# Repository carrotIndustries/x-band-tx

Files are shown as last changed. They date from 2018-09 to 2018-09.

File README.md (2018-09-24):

# X Band Transmitter

This project has been my master thesis at the University of Stuttgart at the Institute of Robust Power Semiconductor Systems (ILH) and the Institute of Space Systems (IRS). It's part of larger project of developing a data downlink system (DDS) for an upcoming small satellite.

The transmitter supports a bandwidth of approx 50 MHz at center frequency of nominally 10.475 GHz. Complex baseband data is played back from a 32 KiSa block RAM in the FPGA. For writing data to the block RAM and setting up PLL and DAC, a USB/SPI bridge is included on the board.

I'd like to thank my tutors for allowing me to use my back then largely untested EDA package horizon EDA. Thanks to them I've now got a project to show off what horizon EDA is capable of.

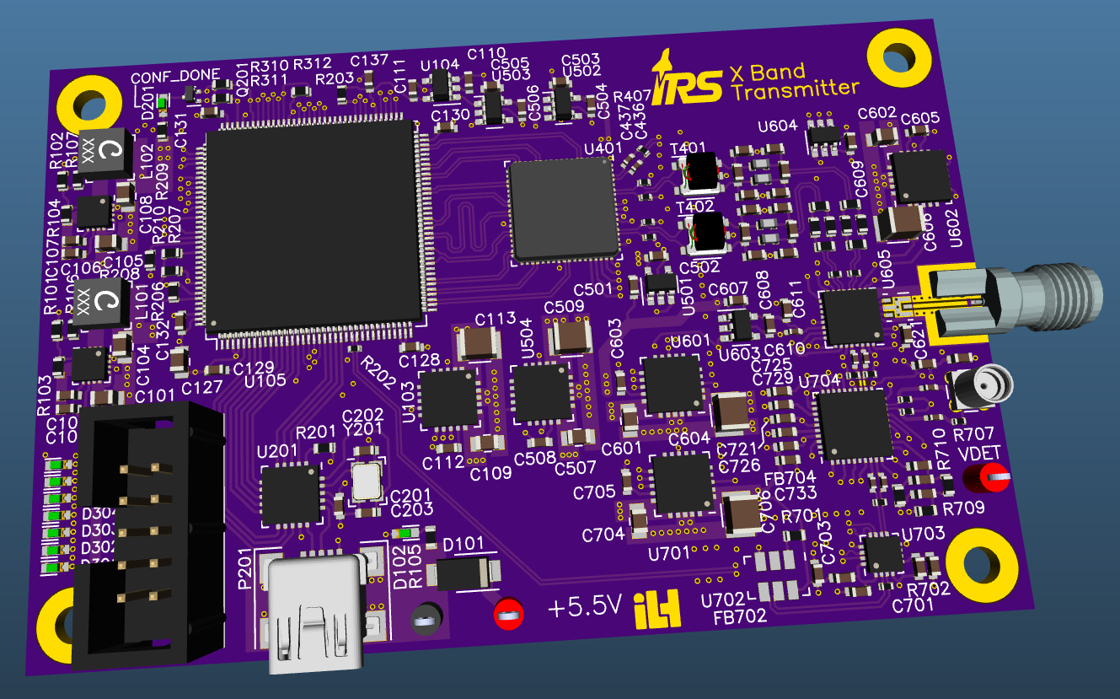
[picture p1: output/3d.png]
PCB


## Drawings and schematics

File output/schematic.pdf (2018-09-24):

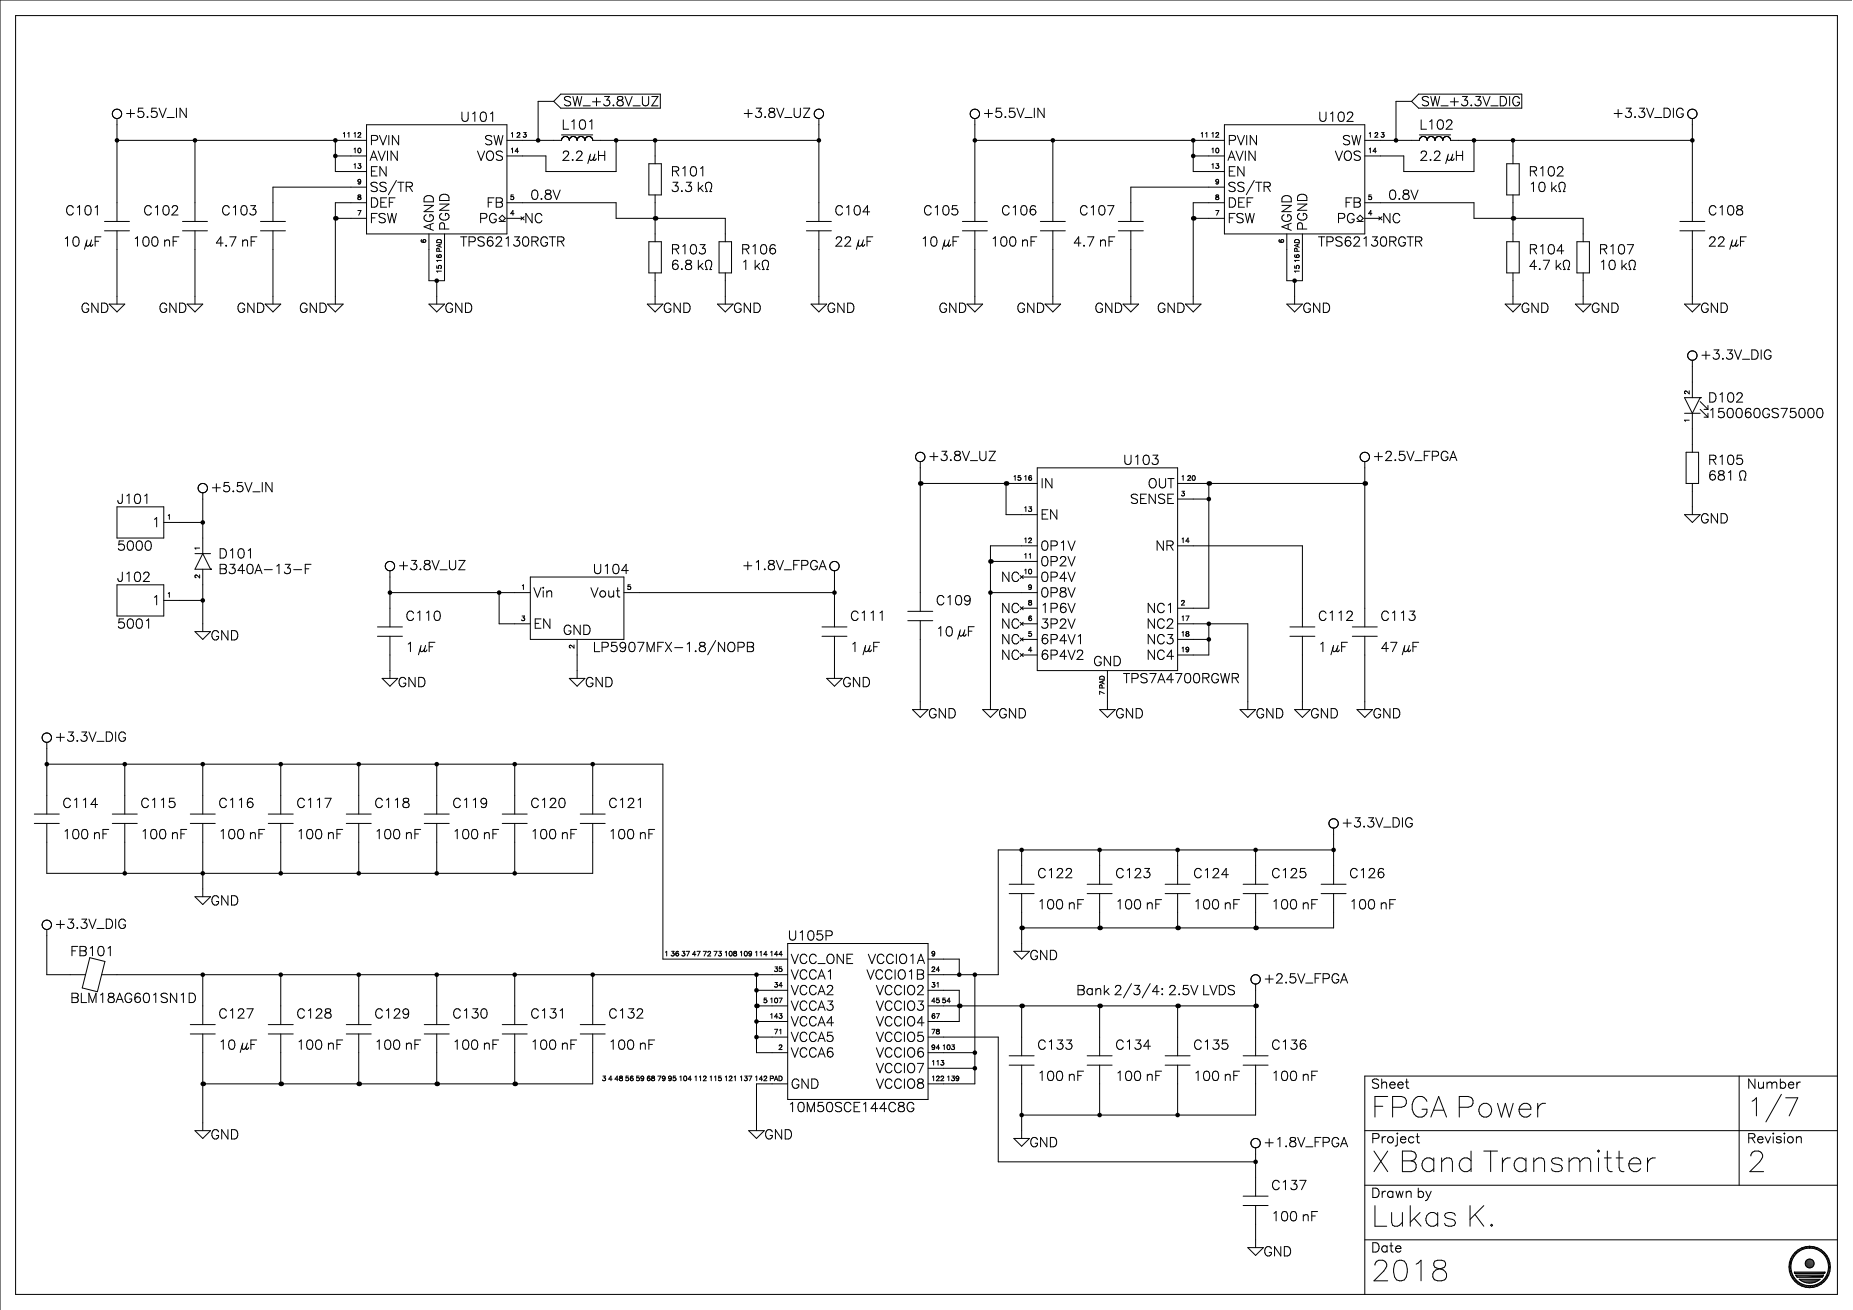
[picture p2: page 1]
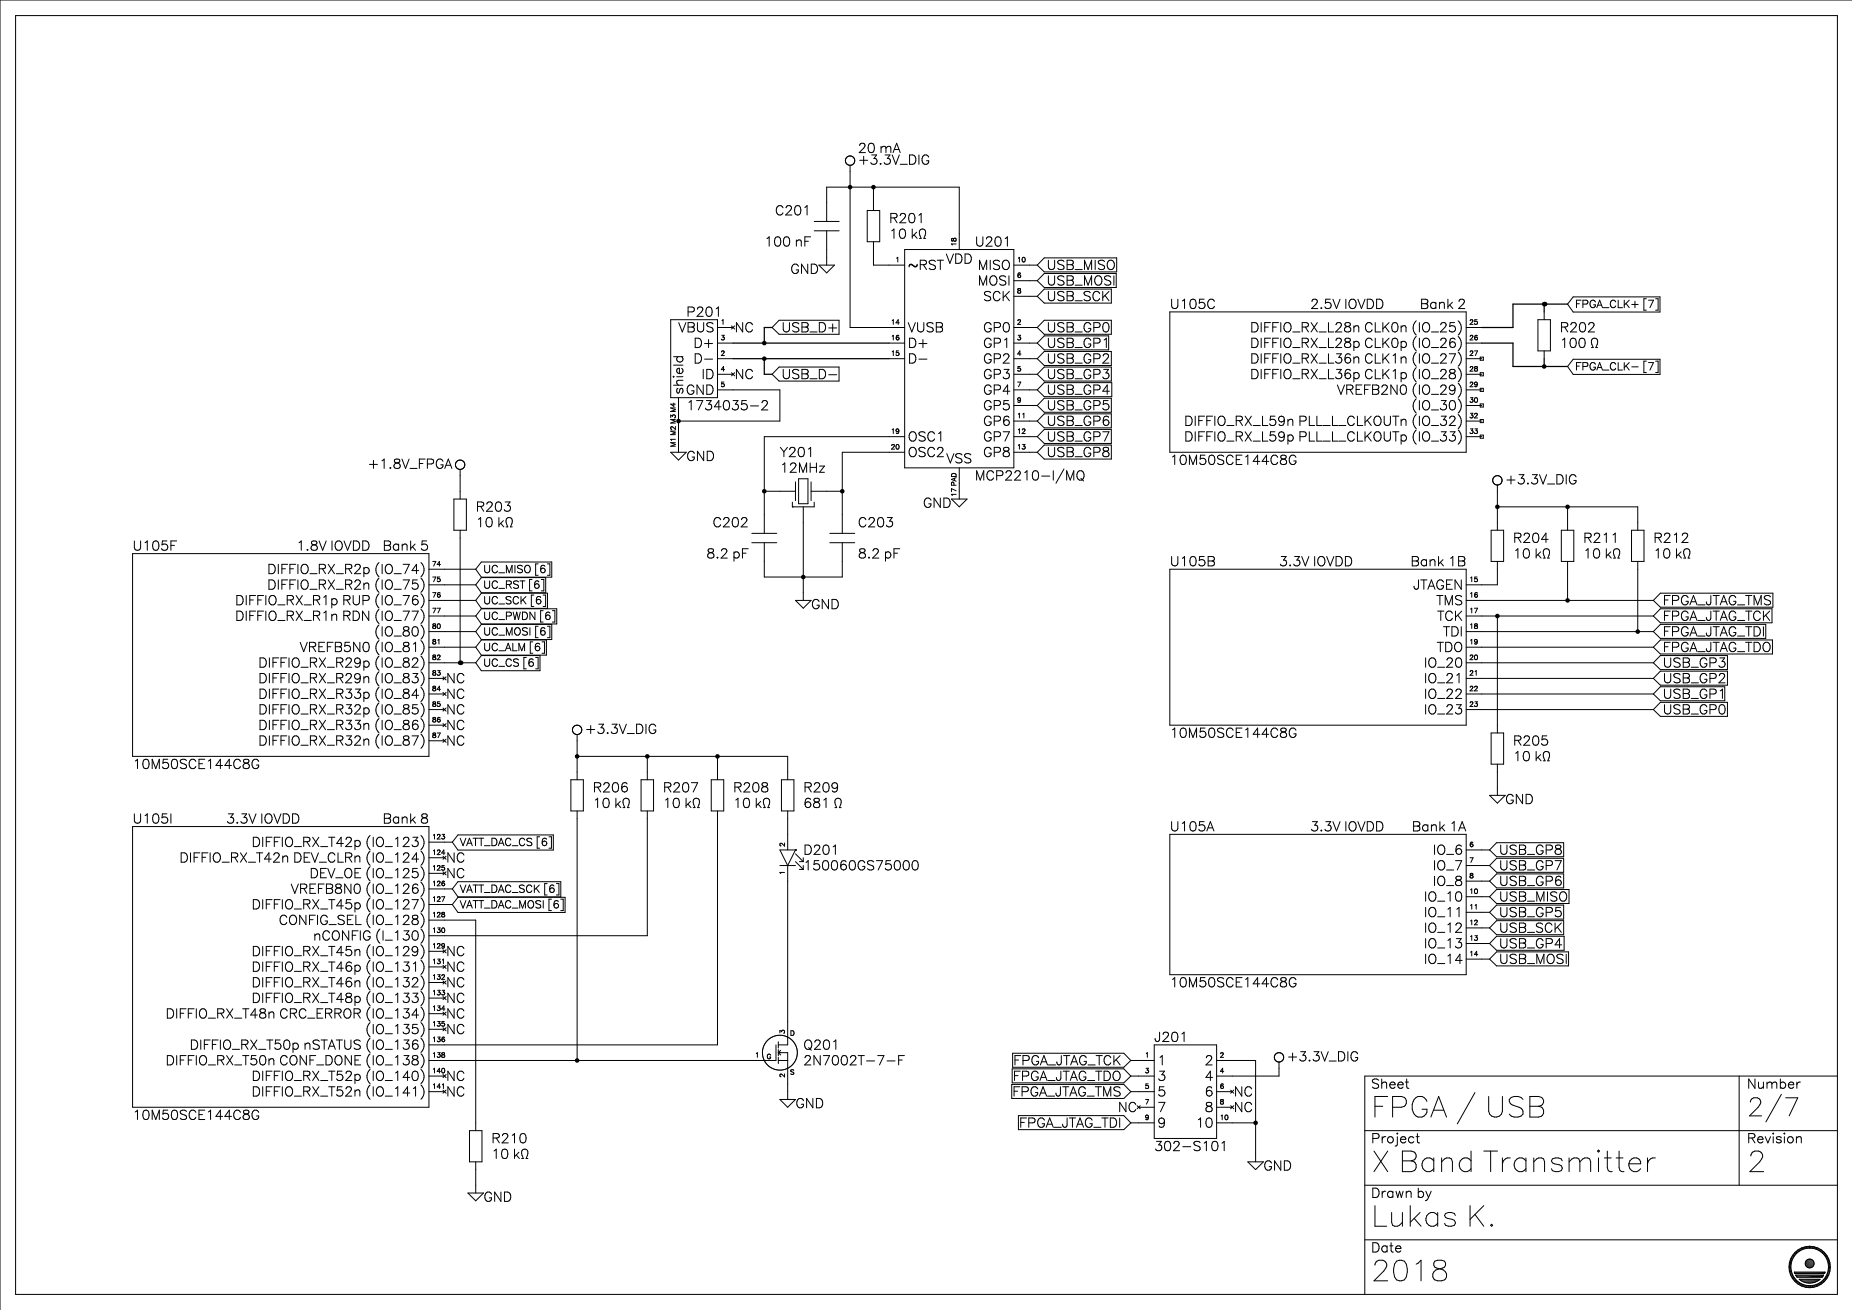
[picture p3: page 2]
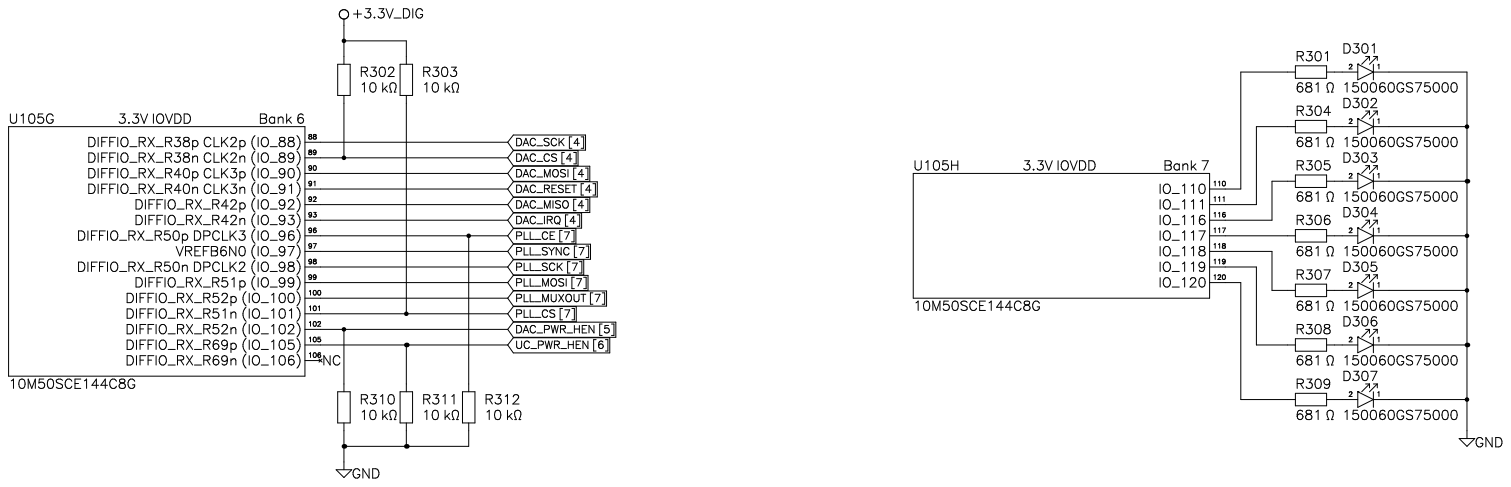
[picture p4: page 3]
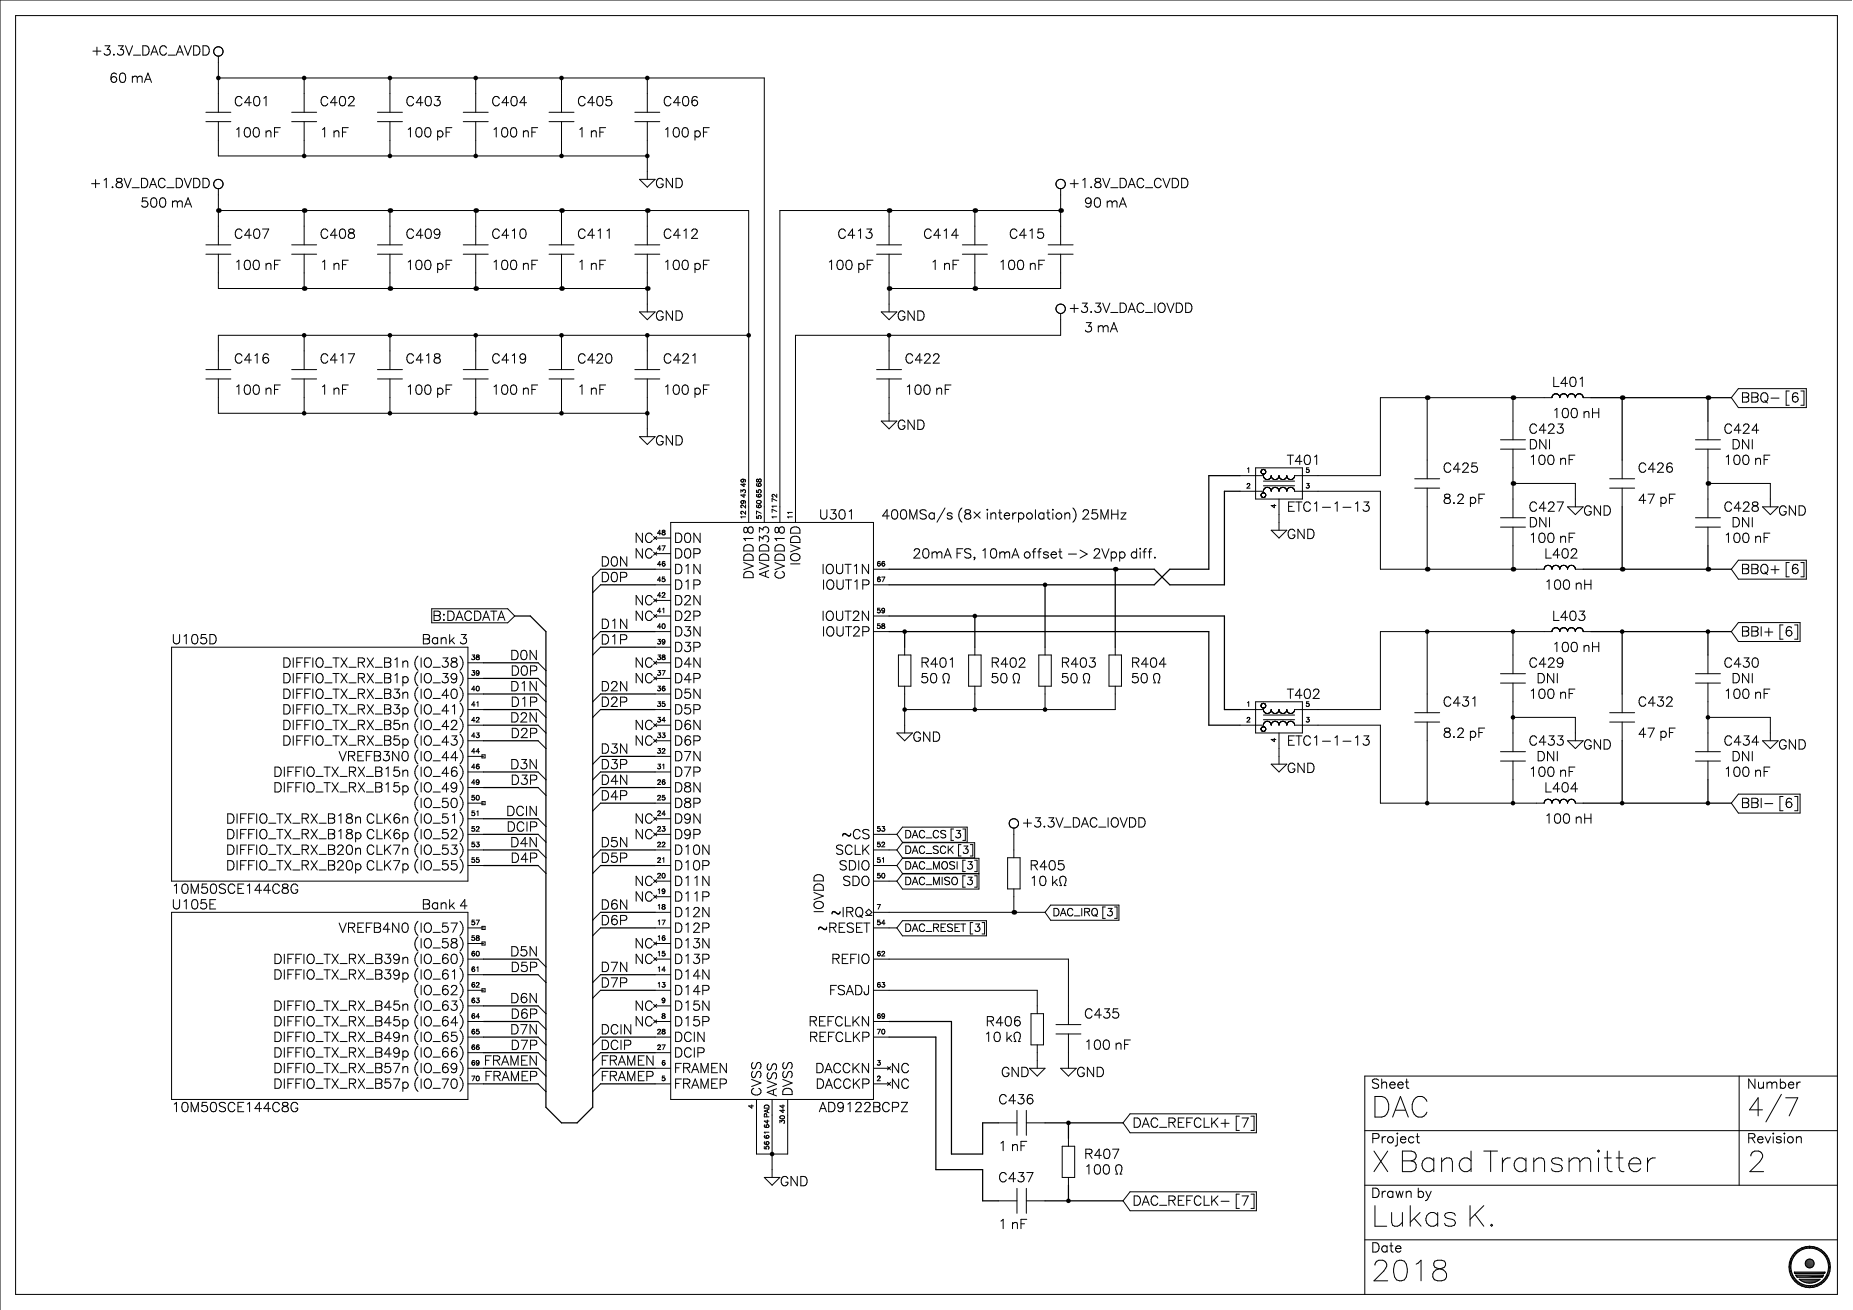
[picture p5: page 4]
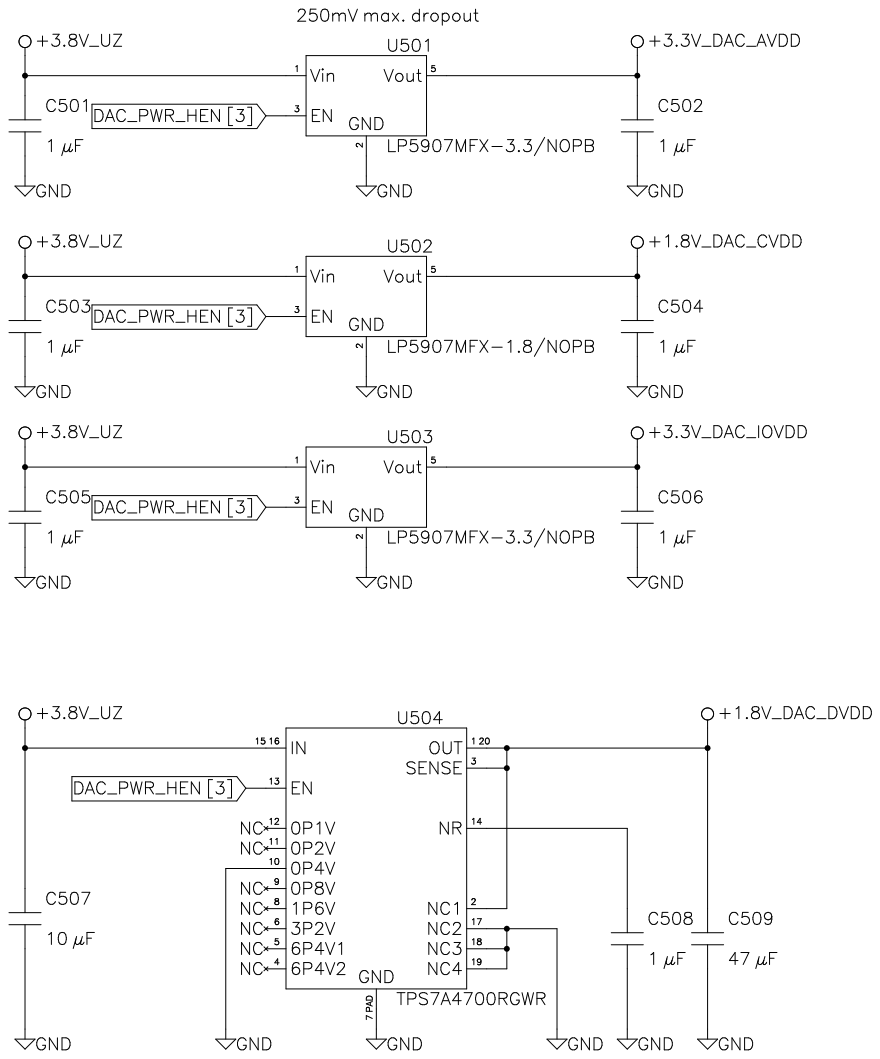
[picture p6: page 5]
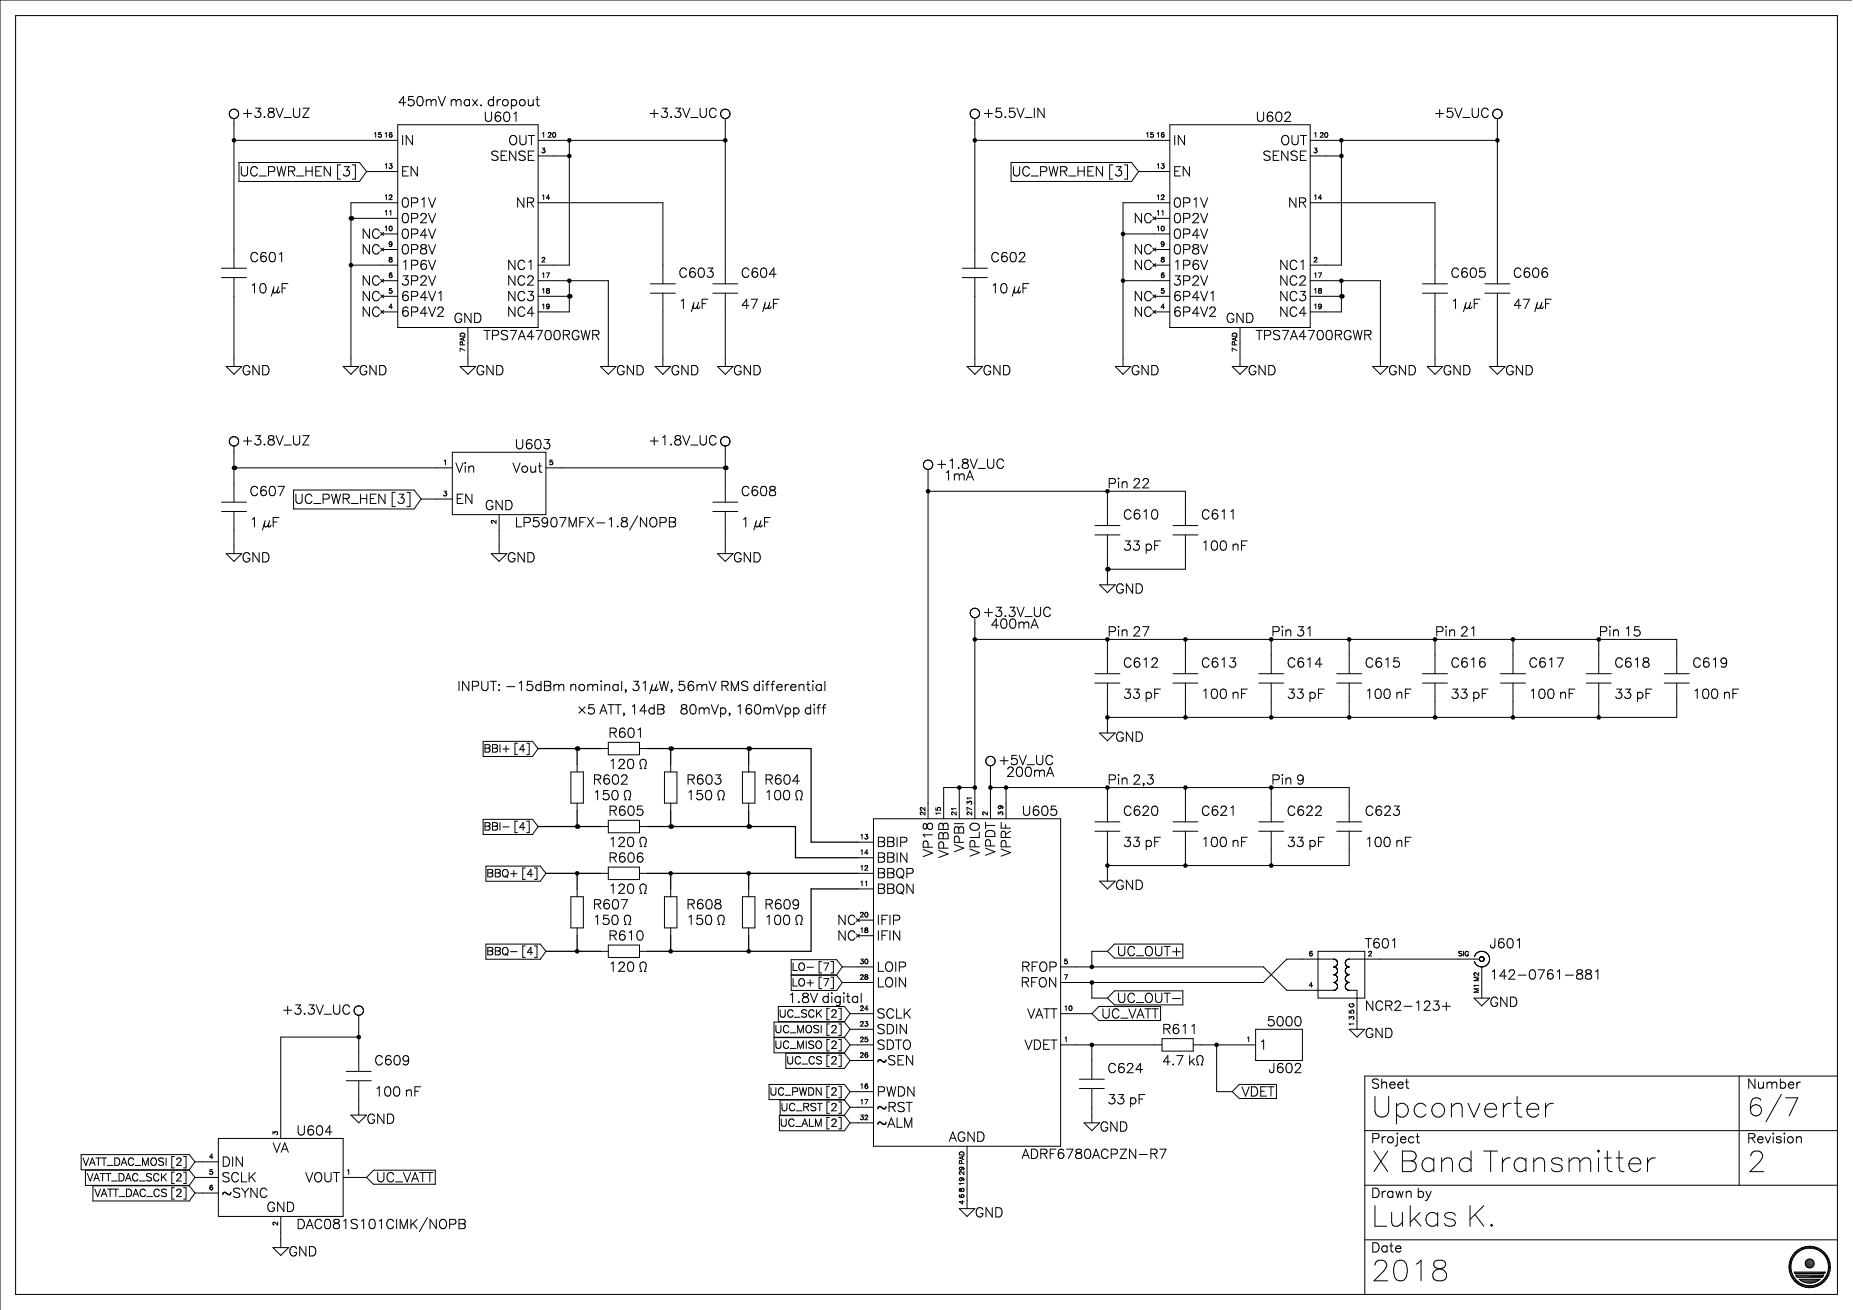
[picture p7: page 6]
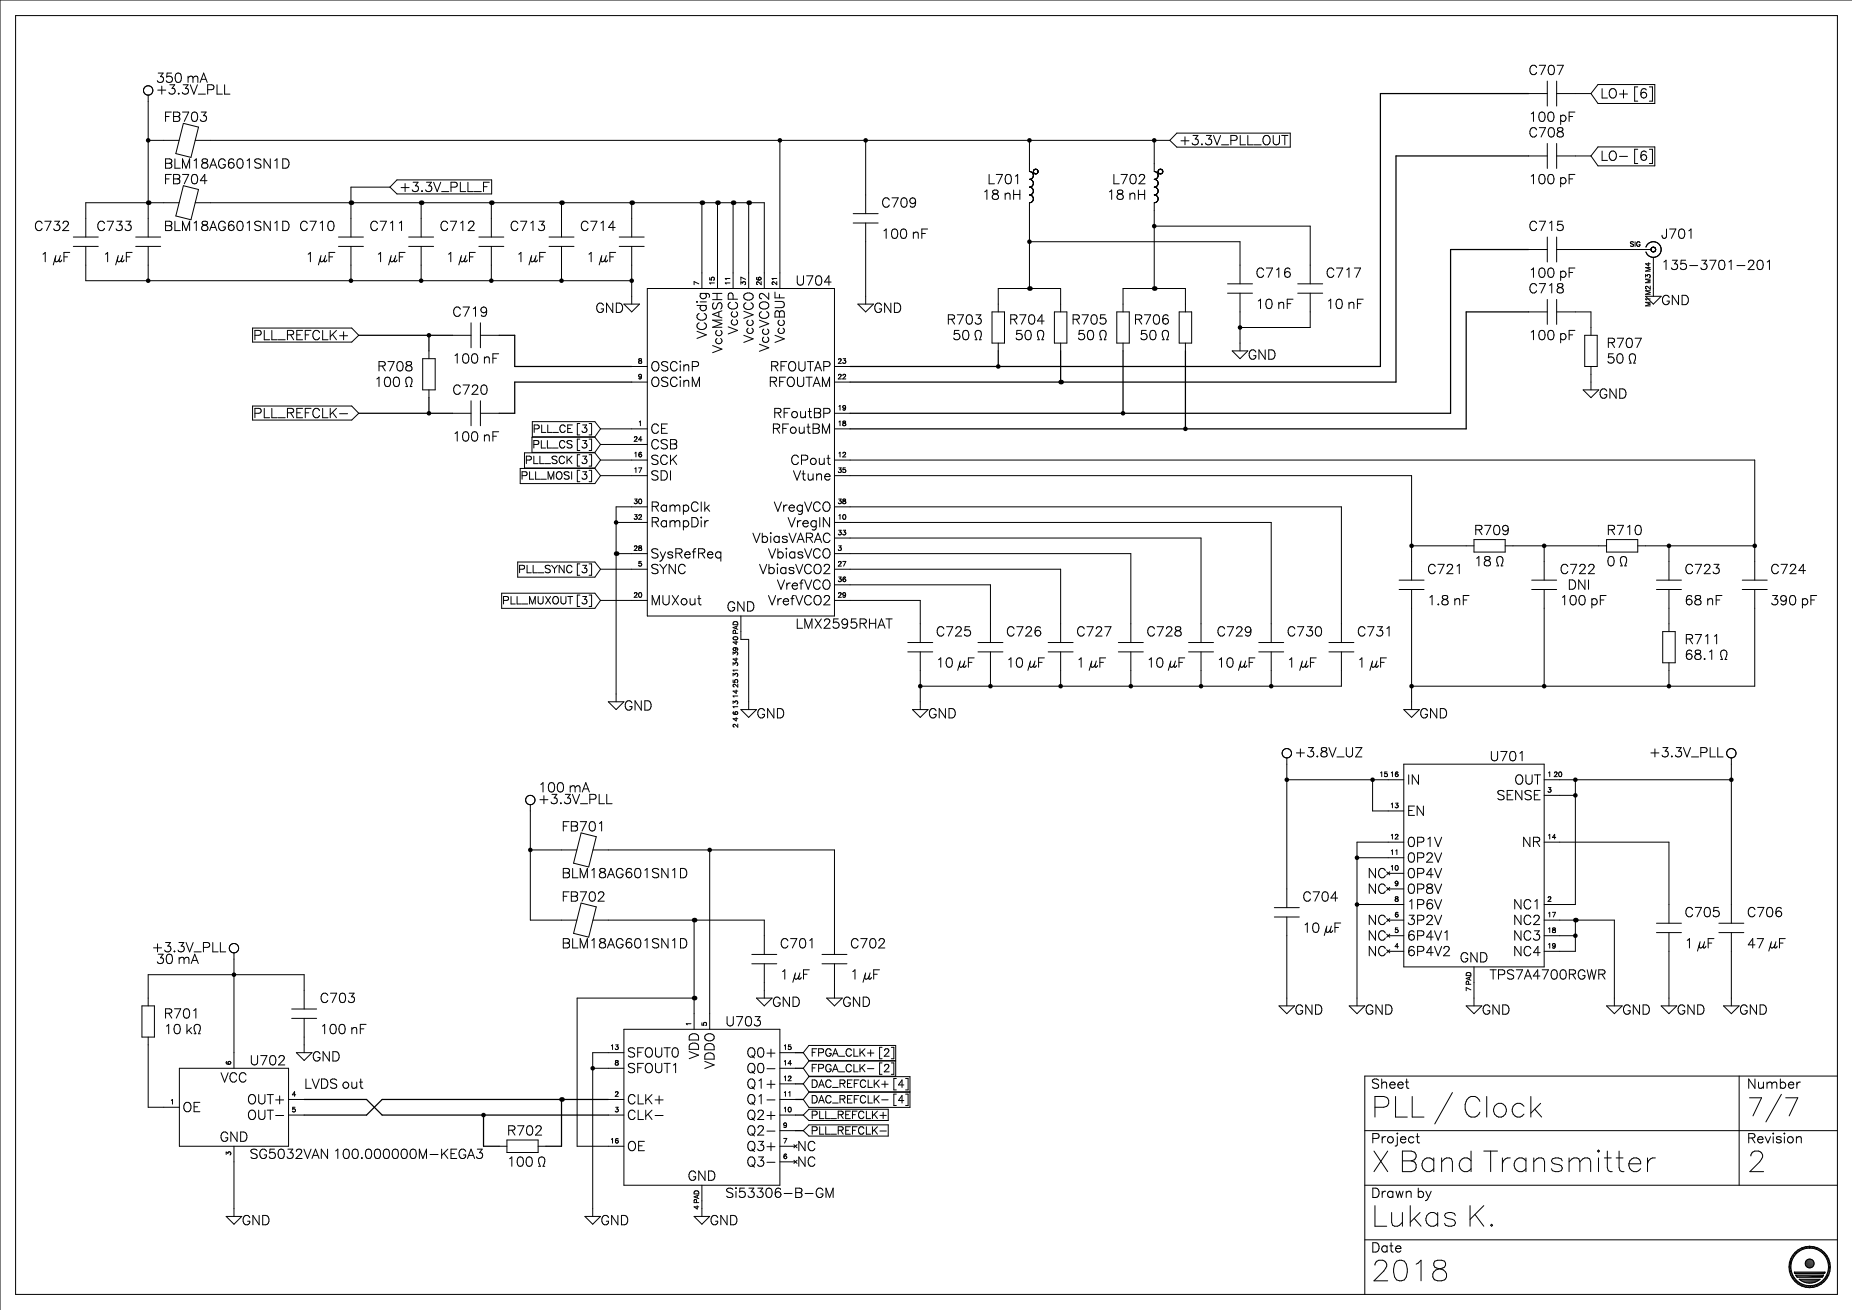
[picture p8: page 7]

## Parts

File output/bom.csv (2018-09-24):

QTY | MPN | Manufacturer | Value | Ref. Des. | Package | Description
8 | CPL-CAP-X5R-0805-10UF-16V | CPL | 10 µF | C101, C105, C109, C127, C507, C601, C602, C704 | C0805
53 | CPL-CAP-X7R-0603-100NF-50V | CPL | 100 nF | C102, C106, C114, C115, C116, C117, C118, C119, C120, C121, C122, C123, C124, C125, C126, C128, C129, C130, C131, C132, C133, C134, C135, C136, C137, C201, C401, C404, C407, C410, C415, C416, C419, C422, C423, C424, C427, C428, C429, C430, C433, C434, C435, C609, C611, C613, C615, C617, C619, C621, C623, C703, C709 | C0603
2 | CPL-CAP-X7R-0603-4.7NF-50V | CPL | 4.7 nF | C103, C107 | C0603
2 | CPL-CAP-X5R-0805-22UF-6.3V | CPL | 22 µF | C104, C108 | C0805
27 | CPL-CAP-X7R-0603-1UF-25V | CPL | 1 µF | C110, C111, C112, C501, C502, C503, C504, C505, C506, C508, C603, C605, C607, C608, C701, C702, C705, C710, C711, C712, C713, C714, C727, C730, C731, C732, C733 | C0603
5 | C1210C476M4PACTU | KEMET | 47 µF | C113, C509, C604, C606, C706 | C1210 | SMD MLCC, X5R Dielectric, 4 – 50 VDC
4 | C0603C829D5GACTU | KEMET | 8.2 pF | C202, C203, C425, C431 | C0603 | SMD MLCC, C0G Dielectric, 10 – 250 VDC
9 | CPL-CAP-X7R-0402-1NF-50V | CPL | 1 nF | C402, C405, C408, C411, C414, C417, C420, C436, C437 | C0402
7 | HMK105CG101JV-F | Taiyo Yuden | 100 pF | C403, C406, C409, C412, C413, C418, C421 | C0402 | Multilayer ceramic capacitor
2 | C0603C470F1GACTU | KEMET | 47 pF | C426, C432 | C0603 | SMD MLCC, C0G Dielectric, 10 – 250 VDC
8 | HMK105CG330JV-F | Taiyo Yuden | 33 pF | C610, C612, C614, C616, C618, C620, C622, C624 | C0402 | Multilayer ceramic capacitor
4 | CBR04C101F3GAC | KEMET | 100 pF | C707, C708, C715, C718 | C0402 | HiQ-CBR Series, C0G Dielectric, Low ESR 6.3 – 500 VDC, 1 MHz – 50 GHz
2 | CPL-CAP-X7R-0603-10NF-50V | CPL | 10 nF | C716, C717 | C0603
2 | CPL-CAP-X7R-0402-100NF-16V | CPL | 100 nF | C719, C720 | C0402
1 | C0603C182J5GACTU | KEMET | 1.8 nF | C721 | C0603 | SMD MLCC, C0G Dielectric, 10 – 250 VDC
1 | CPL-CAP-C0G-0603-100PF-50V | CPL | 100 pF | C722 | C0603
1 | C0603C683J5RACTU | KEMET | 68 nF | C723 | C0603 | SMD MLCC, C0G Dielectric, 10 – 250 VDC
1 | C0603C391F5GACTU | KEMET | 390 pF | C724 | C0603 | SMD MLCC, C0G Dielectric, 10 – 250 VDC
4 | LMK107BJ106MALTD | Taiyo Yuden | 10 µF | C725, C726, C728, C729 | C0603 | Multilayer ceramic capacitor
1 | B340A-13-F | Diodes Inc. | B340A-13-F | D101 | SMA | 3.0A surface mount schottky barrier rectifier
9 | 150060GS75000 | Würth Elektronik | 150060GS75000 | D102, D201, D301, D302, D303, D304, D305, D306, D307 | 0603 LED | LED green clear 0603 SMD
5 | BLM18AG601SN1D | Murata | BLM18AG601SN1D | FB101, FB701, FB702, FB703, FB704 | C0603 | Ferrite bead, 600 Ohm @ 100 MHz, 500 mA
2 | 5000 | Keystone | 5000 | J101, J602 | 5000 | Miniature THM Test Point - Red
1 | 5001 | Keystone | 5001 | J102 | 5000 | Miniature THM Test Point - Black
1 | 302-S101 | On Shore Technology | 302-S101 | J201 | IDC header 2×5, 2.54mm pitch, vertical | IDC header 2×5, 2.54mm pitch, vertical
1 | 142-0761-881 | Cinch Connectivity Solutions | 142-0761-881 | J601 | 142-0761-881 | Edge launch SMA connector
1 | 135-3701-201 | Cinch Connectivity Solutions | 135-3701-201 | J701 | 135-3701-201 | MMCX Jack, Straight PCB Mount
2 | XFL4020-222MEC | Coilcraft | 2.2 µH | L101, L102 | XFL4020 | Shielded Power Inductor
4 | LQW18ANR10G00D | Murata | 100 nH | L401, L402, L403, L404 | LQW18AN_00 | Wirewound chip inductor
2 | LQG15HS18NJ02D | Murata | 18 nH | L701, L702 | L0402 (polarized) | Inductor 18 nH, 400 mA, 0.36 Ω
1 | 1734035-2 | TE Connectivity | 1734035-2 | P201 | 1734035-2 | Mini USB-B receptacle
1 | 2N7002T-7-F | Diodes Inc. | 2N7002T-7-F | Q201 | SOT-523 | N-channel enhancement mode MOSFET
1 | CPL-RES-0603-3.3K-0.1W | CPL | 3.3 kΩ | R101 | R0603
20 | CPL-RES-0603-10K-0.1W | CPL | 10 kΩ | R102, R107, R201, R203, R204, R205, R206, R207, R208, R210, R211, R212, R302, R303, R310, R311, R312, R405, R406, R701 | R0603
1 | CPL-RES-0603-6.8K-0.1W | CPL | 6.8 kΩ | R103 | R0603
2 | CPL-RES-0603-4.7K-0.1W | CPL | 4.7 kΩ | R104, R611 | R0603
9 | CPL-RES-0603-681-0.1W | CPL | 681 Ω | R105, R209, R301, R304, R305, R306, R307, R308, R309 | R0603
1 | CPL-RES-0603-1K-0.1W | CPL | 1 kΩ | R106 | R0603
6 | CPL-RES-0402-100-0.063W | CPL | 100 Ω | R202, R407, R604, R609, R702, R708 | R0402
4 | CRCW040249R9FKEDC | Vishay | 50 Ω | R401, R402, R403, R404 | R0402 | Thick Film Chip Resistor
4 | CPL-RES-0603-120-0.1W | CPL | 120 Ω | R601, R605, R606, R610 | R0603
4 | CPL-RES-0603-150-0.1W | CPL | 150 Ω | R602, R603, R607, R608 | R0603
5 | FC0402E50R0BST1 | Vishay | 50 Ω | R703, R704, R705, R706, R707 | R0402 | High Frequency (up to 40 GHz) Resistor
1 | RC0603FR-0718RL | Yageo | 18 Ω | R709 | R0603 | General Purpose Chip resistor
1 | CPL-RES-0603-0-0.1W | CPL | 0 Ω | R710 | R0603
1 | CPL-RES-0603-68.1-0.1W | CPL | 68.1 Ω | R711 | R0603
2 | ETC1-1-13 | Macom | ETC1-1-13 | T401, T402 | ETC1-1-13 | 1:1 Transmission line transformer 4.5 - 3000 MHz
1 | NCR2-123+ | Minicircuits | NCR2-123+ | T601 | NF1846-1 | RF transformer 4700 to 12000 MHz
2 | TPS62130RGTR | Texas Instruments | TPS62130RGTR | U101, U102 | RGT | 3 V to 17 V, 3A Step-Down Converter
5 | TPS7A4700RGWR | Texas Instruments | TPS7A4700RGWR | U103, U504, U601, U602, U701 | RGW | 36 V, 1 A, 4 µV RMS , RF LDO Voltage Regulator
3 | LP5907MFX-1.8/NOPB | Texas Instruments | LP5907MFX-1.8/NOPB | U104, U502, U603 | DBV | 250 mA Ultra-Low-Noise, Low Iq LDO
1 | 10M50SCE144C8G | Intel | 10M50SCE144C8G | U105 | EQFP-144 | MAX 10 FPGA
1 | MCP2210-I/MQ | Microchip | MCP2210-I/MQ | U201 | RGW | USB-to-SPI Protocol Converter with GPIO (Master Mode)
1 | AD9122BCPZ | Analog Devices | AD9122BCPZ | U401 | CP-72-7 | Dual 16-Bit, 1230 MSa/s DAC
2 | LP5907MFX-3.3/NOPB | Texas Instruments | LP5907MFX-3.3/NOPB | U501, U503 | DBV | 250 mA Ultra-Low-Noise, Low Iq LDO
1 | DAC081S101CIMK/NOPB | Texas Instruments | DAC081S101CIMK/NOPB | U604 | DDC | 8-Bit µPower DAC
1 | ADRF6780ACPZN-R7 | Analog Devices | ADRF6780ACPZN-R7 | U605 | QFN-32 | 5.9 GHz - 23.6 GHz Upconverter
1 | SG5032VAN 100.000000M-KEGA3 | EPSON | SG5032VAN 100.000000M-KEGA3 | U702 | SG5032 | Crystal Oscillator 100 MHz LVDS output
1 | Si53306-B-GM | Silicon Labs | Si53306-B-GM | U703 | QFN-16 | 1 : 4 low-jitter buffer/level translator
1 | LMX2595RHAT | Texas Instruments | LMX2595RHAT | U704 | RHA | 19 GHz Wideband RF Synthesizer
1 | NX3225SA-12.000M-STD-CRS-2 | NDK | 12MHz | Y201 | 4-SMD 3.2×2.5mm | 12 MHz 8 pF SMD crystal oscillator
